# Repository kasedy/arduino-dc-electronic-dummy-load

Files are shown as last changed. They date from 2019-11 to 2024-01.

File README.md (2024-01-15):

# Arduino DIY: constant current electronic dummy load 

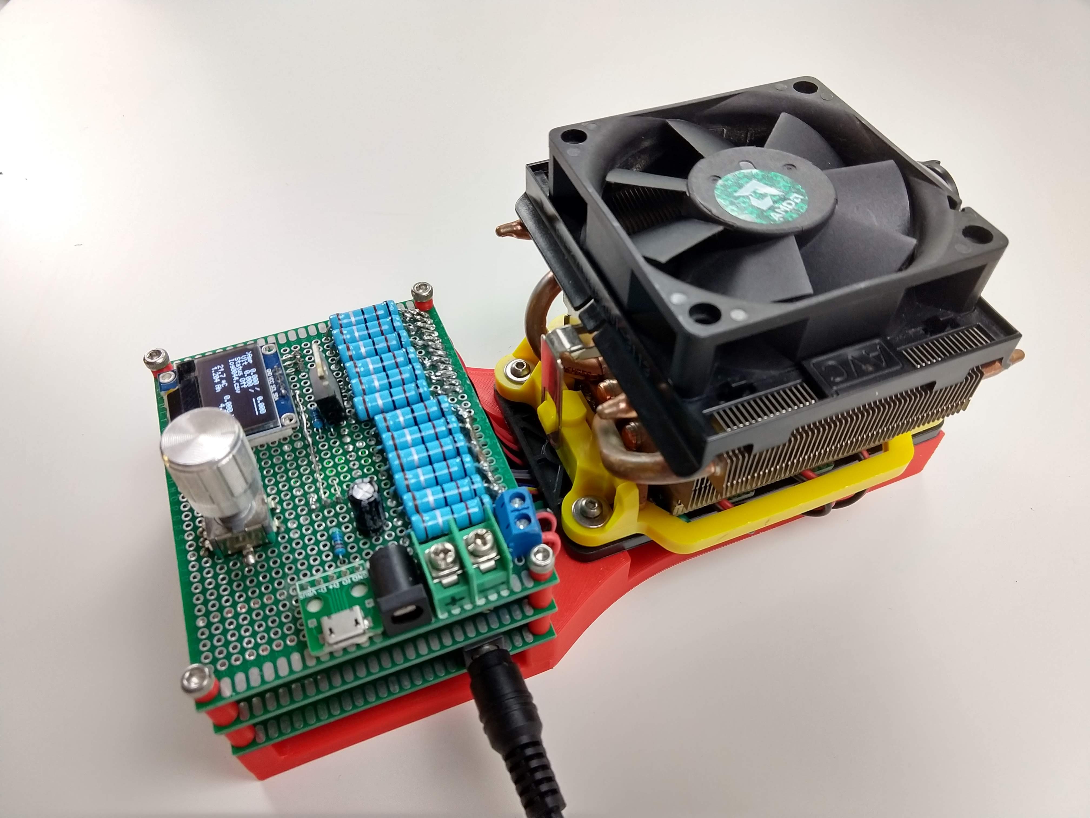
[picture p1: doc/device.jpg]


# Absolute Maximum Ratings

* Maximum Input Load Voltage - 32V
* Maximum Input Load Current - 16A
* Maximum Input Power Dissapation - 120W
* Power Source - 12V power addapter
* Minimum load current draw - 50mA
* Constant current resolution - 1mA
* Current reading error (limited by INA219 ADC resolution) - 5mA
* Voltage reading error (limited by INA219 ADC resolution) - 5mV

# Features

* Doesn't require PCB manufacturing and can be assembled on a perf board
* Multi layer stacked design to reduce the circuit size
* Using prebuilt Arduino modules reduces assemble effort
* Bright OLED display with intuitive user interface
* Writes discharge current and voltage values into microSD card
* Fully customizable

# Part list
1. 12V fan with a heat sink. It should have PWM speed control function. I used stock CPU fan from AMD FX-8350 processor as it was laying in a junk box for a long time after I installed water cooling to my desctop PC.
2. CPU cooling Fan Holder for AMD AM3. Bought on [Aliexpress](https://www.aliexpress.com/wholesale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).
3. Resistor 0.1R 3W - 12 pices. [Aliexpress](https://www.aliexpress.com/wholesale?catId=0&initiative_id=SB_20191124000008&SearchText=Resistor+0.1+3W)
4. Arduino nano. [Aliexpress](https://www.aliexpress.com/wholesale?catId=0&initiative_id=SB_20191124000043&SearchText=Arduino+nano)
5. Electrolytic capacitors 470uf and 47uf (2 pcs)
6. High current logic level N-Channel mosfet. I used IRF1404 (7 pcs) as it have ultra low On-Resistance.
7. Logic level mosfet to switch on and off the fan. I used AO3400 with a SOT23-to-DIP adapter PCB.
8. Male, female and 90-degree bended pin headers.
9. Rotary encoder.
10. SSD1306 LCD display
11. Diode to restrict reverse current coming from the fan. I belive pretty much any will work. I used M1 smd diode. But through-hole will also fit.
12. INA219 module will measure voltage and current.
13. MicroSD card module.
14. Some 2mm duck tape to palce as a buffer between perboard and arduino modules.
15. LM385P dual operational amplifier (3 pcs) and hole female header
16. Bunch of 1/4W through-hole resistors.
17. 7x9 cm perfboard (4 pcs)
18. Thermal conductive paste or tape.
19. Wire.
20. Connectors KF7.62, KF301-5.0-2P, 5.5x2.1mm Female DC Power Jack, 
21. 1kOm potentiometer.
22. 40mm M3 screw (4 pcs).
23. I used thermistor to measure heat sink temperature, but LM35 temperature sensor will be the easier solution as it doesn't requere calibration.

# Tools
1. Soldering iron
2. Flux
3. Soldering wire
4. Multimeter

# Assembly instructions

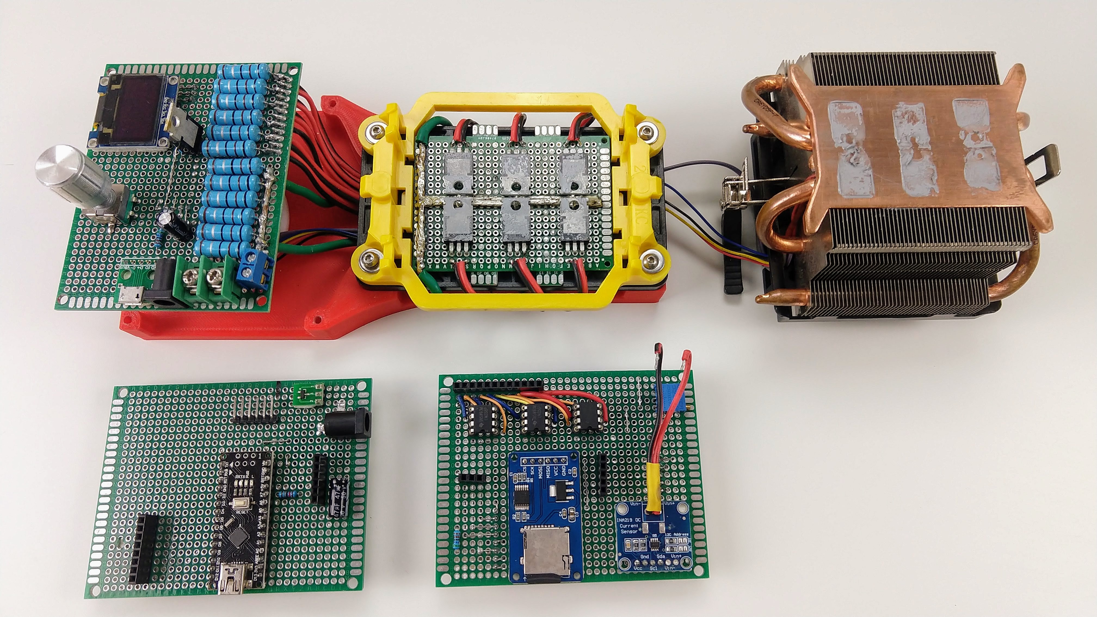
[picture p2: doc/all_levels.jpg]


# Design justification

## 12V power supply
12V power supply is less convinient than 5V but there are several reasons why it was used. First of all LM385 operational amplifier shows more stable work when powered from 12V. Also it allows to use much bigger variety of N-channel MOSFET as a heat element with a gate voltage hight than 5V and not to be bound to logic level MOSFET. The other reason is that PC fans work from 12v.

## 120W is not enough
Current design utilize 6 cascades. Each cascade includes opperational amplifier, 0R1 resistor and n-channel MOSFET. Cheap low-quality MOSFETs from Aliexpress can handle about 20W. You can get better MOSFET transistor or add more cascades. Feel free to extend the design.

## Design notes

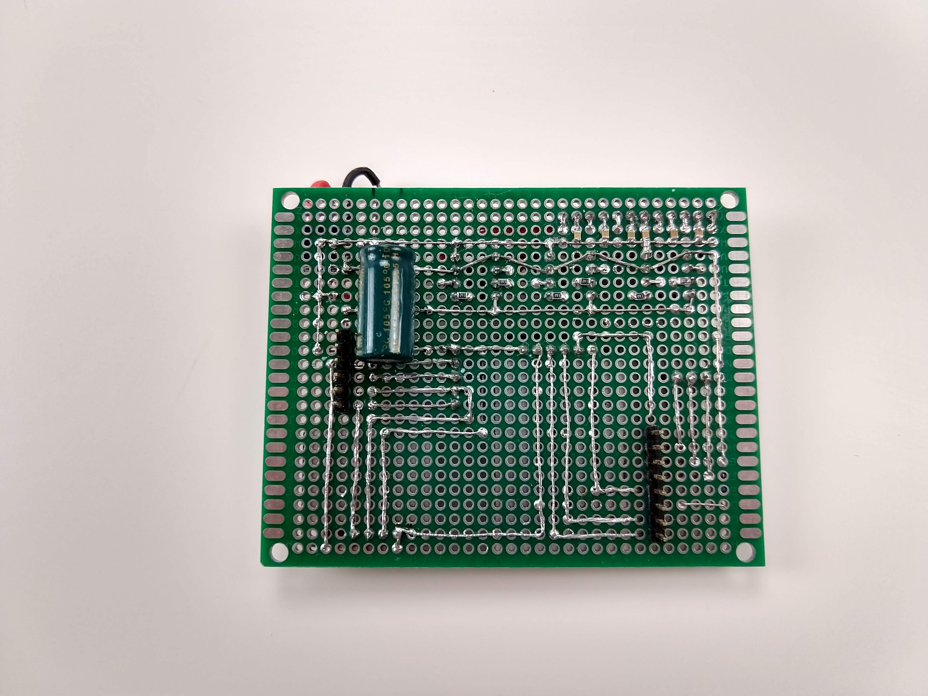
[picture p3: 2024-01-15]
doc/level_2/IMG_20191124_163301046_HDR.jpg

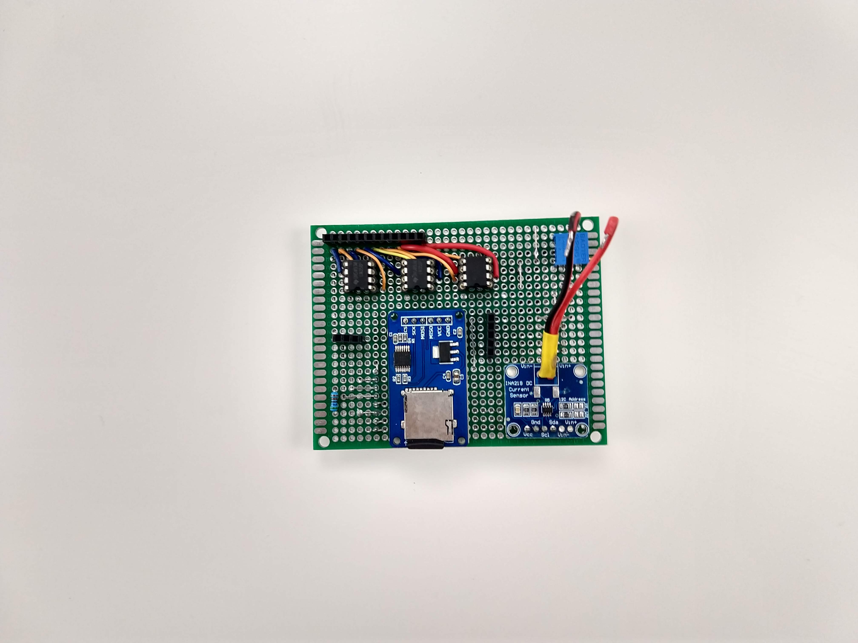
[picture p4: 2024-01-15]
doc/level_2/IMG_20191124_163133878_HDR.jpg

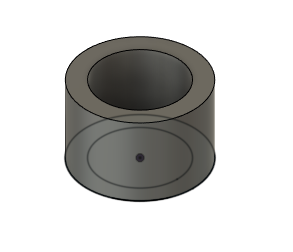
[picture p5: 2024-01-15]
doc/3d models/spacer.png

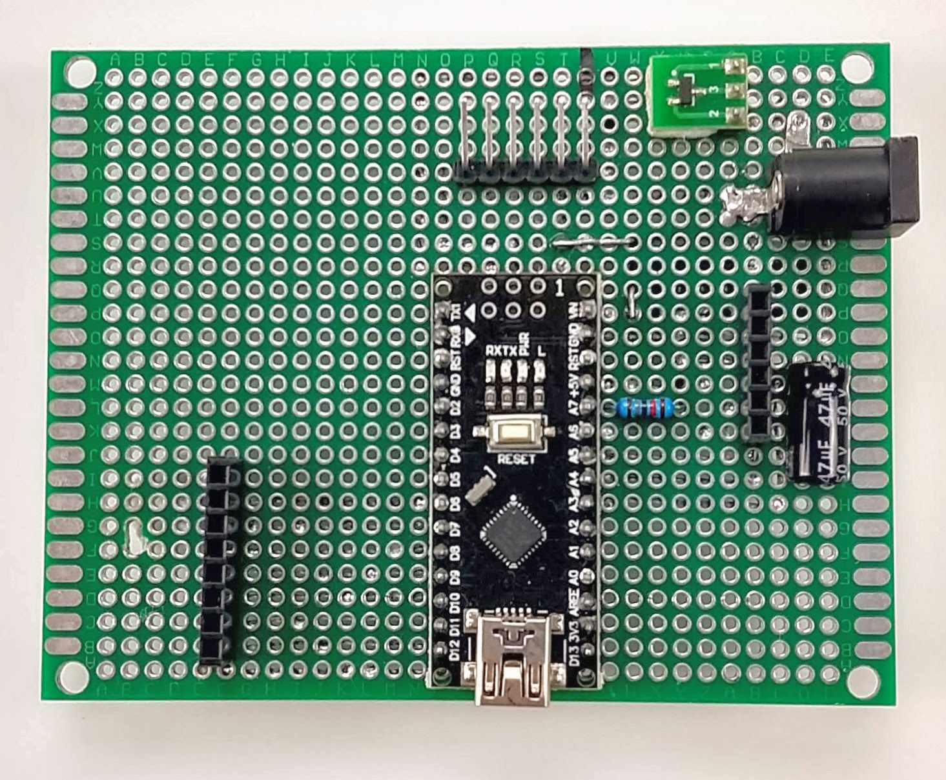
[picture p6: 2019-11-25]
doc/level_1/front.jpg

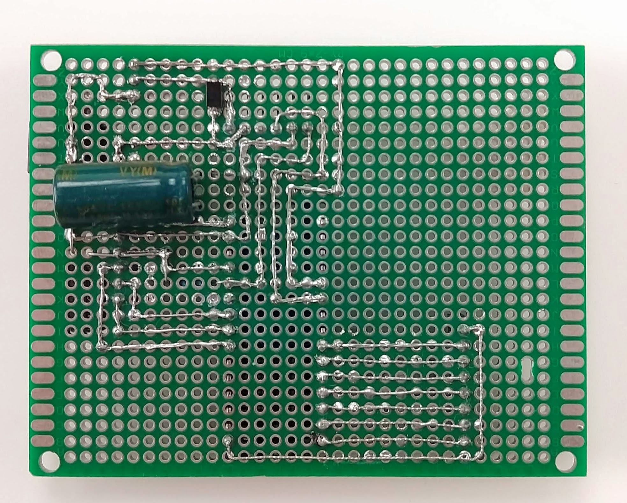
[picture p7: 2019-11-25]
doc/level_1/back.jpg

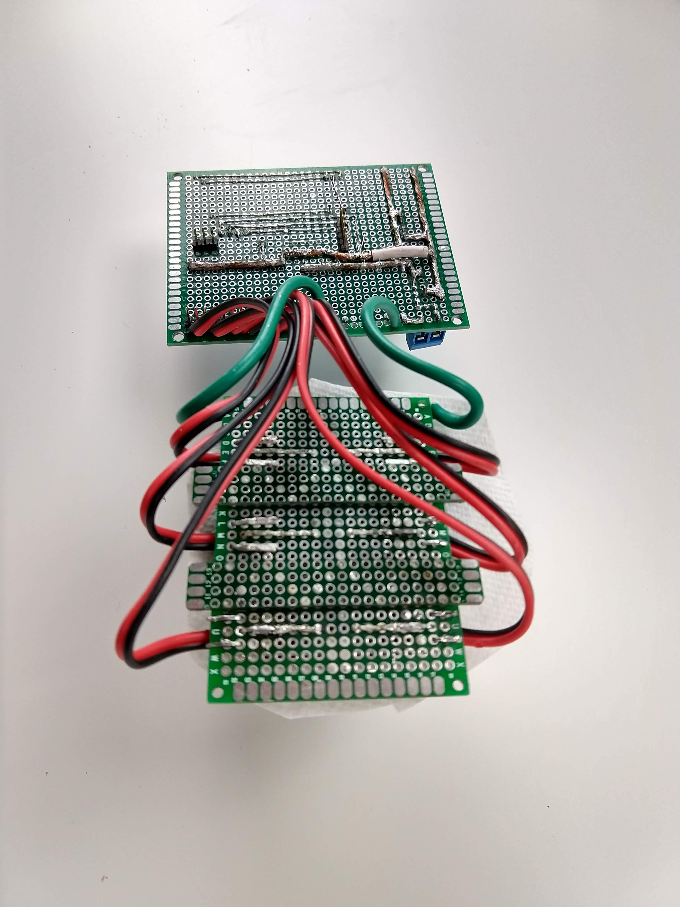
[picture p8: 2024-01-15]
doc/level_3/IMG_20191124_163827577_HDR.jpg

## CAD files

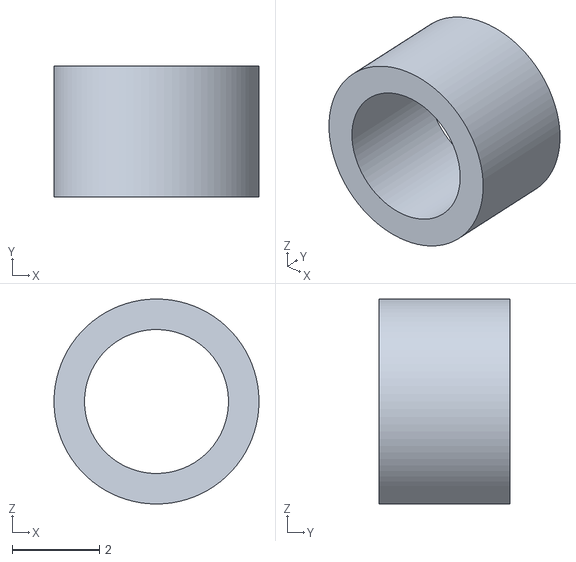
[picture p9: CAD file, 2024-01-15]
doc/3d models/spacer.stl
4.70 x 3.00 x 4.70

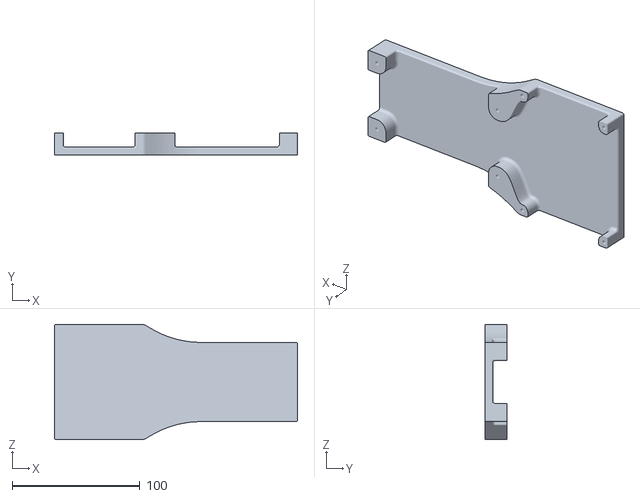
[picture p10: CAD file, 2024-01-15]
doc/3d models/foundation.stl
190.0 x 17.0 x 90.0

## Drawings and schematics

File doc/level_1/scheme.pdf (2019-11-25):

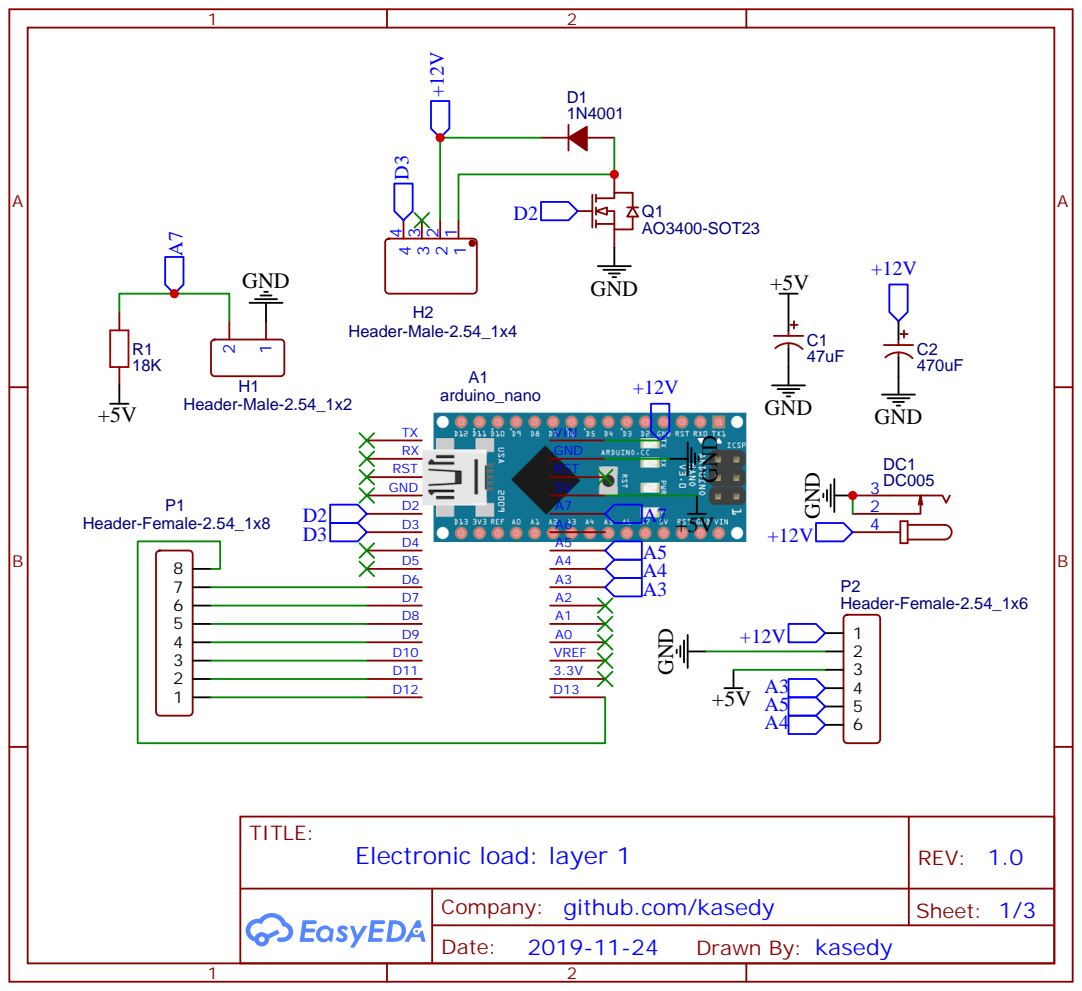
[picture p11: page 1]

Company: github.com/kasedy

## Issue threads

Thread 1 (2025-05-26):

Lack of detail

StasDeSante, 2025-05-26:
Hey, I'm currently trying to give your electronic load a go. But the lack of information in here is soul crushing. Maybe you could release a schematic or anything really? 🥺

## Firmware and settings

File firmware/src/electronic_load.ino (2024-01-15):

#include <Wire.h>
#include <ClickEncoder.h>
#include <SSD1306Ascii.h>
#include <SSD1306AsciiWire.h>
#include <MemoryFree.h>

#include "constants.h"
#include "menu_navigator.h"
#include "system_state.h"
#include "managers.h"

SSD1306AsciiWire oled;

ClickEncoder encoder(ENCODER_PIN_LEFT,
                     ENCODER_PIN_RIGHT,
                     ENCODER_PIN_BTN,
                     4);

uint32_t lastGaugeUpdateTime = 0;
uint32_t loopProcessedLastTime = 0;

MenuNavigator menuNavigator = MenuNavigator(encoder, oled);

ISR(TIMER1_OVF_vect)
{
  encoder.service();
}

void setup() {
  Serial.begin(9600);
  Serial.println(F("Setup Start!"));

  randomSeed(analogRead(UNUSED_ANALOG_PIN));

  PersistenceStateManager::setup();
  AmperagePinManager::setup();
  EmergencyManager::setup();
  FanManager::setup();
  FanTemperatureReader::setup();
  GaugeReader::setup();
  SdCardLogger::setup();

  setupOledDisplay();

  // Timer1 is 16 bit, up to 65536
  // None-inverted mode for pin 10
  TCCR1A = _BV(COM1B1); 
  // Fast PWM mode 14 with ICR1 as TOP, scale x1
  TCCR1A |= _BV(WGM11);
  TCCR1B = _BV(WGM13) | _BV(WGM12) | _BV(CS10); 
  // Frequency = 16MHz / 1 scale / 1 fast mode / 16000 = 1Kz
  ICR1 = MAX_PWM_DUTY_CYCLE;
  // interrupt is attached
  TIMSK1 = _BV(TOIE1); 

  Serial.print(F("Memory left: "));
  Serial.print(freeMemory());
  Serial.println(F(" bytes"));
  Serial.println(F("Setup end! "));

  loopProcessedLastTime = millis();
}

void loop() {
  unsigned long now = millis();

  menuNavigator.processInput();
  GaugeReader::makeMeasurement();
  FanTemperatureReader::makeMeasurement();

  unsigned long timeSinceLastupdate = now - lastGaugeUpdateTime;
  bool isRefreshCycle = timeSinceLastupdate >= REFRESH_INTERVAL_MS;
  if (isRefreshCycle) {  
    lastGaugeUpdateTime = now;
    SystemState::calculateAverage(timeSinceLastupdate);
    FanTemperatureReader::updateAverageTemperatureValue();
  }

  EmergencyManager::updateOnOffState();
  AmperagePinManager::tuneDischargeCurrent(isRefreshCycle);
  menuNavigator.updateOutput();
  FanManager::updateFanSpeed();

  if (isRefreshCycle) {
    SdCardLogger::writeSystemState();
    PersistenceStateManager::preserve();
  }
  
//  SystemState::debugPrint();

//  Serial.println(now - loopProcessedLastTime);
//  loopProcessedLastTime = now;

  SystemState::clearChangeFlag(); // should go the last
}

void setupOledDisplay() {
  Wire.begin();
  oled.begin(&Adafruit128x64, DISPLAY_I2C_ADDRESS);
  oled.setFont(MENU_FONT);
 
  oled.clear();
  oled.setContrast(255);
  oled.setCursor(0, 4);
  oled.print(F("Electronic load v1.1"));
  delay(2000);
  oled.clear();
}

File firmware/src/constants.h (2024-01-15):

#define DISPLAY_I2C_ADDRESS 0x3C
#define INA219_I2C_ADDRESS 0x40

#define MENU_FONT font5x7

#define FONT_W MENU_FONT[2]
#define FONT_H (MENU_FONT[3] + 1)

#define ENCODER_PIN_LEFT 7
#define ENCODER_PIN_RIGHT 8
#define ENCODER_PIN_BTN 6

// Limited by INA219 (+26V)
#define EMERGENCY_VOLTAGE 25000

#define VOLTAGE_REFERENCE 5.08 // 5v pin mesurment gave reference voltage

#define REFRESH_INTERVAL_MS 1000

#define THERMISTOR_PIN A7
#define THERMISTOR_NOMINAL 47900
#define TEMPERATURE_NOMINAL 25
#define B_COEFFICIENT 3950
#define THERMISTOR_SERIES_RESISTOR 17650

#define FAN_PWM_PIN 3 // can not be changed
#define FAN_ON_OFF_PIN 2
#define FAN_START_TEMPERATURE 35
#define FAN_STOP_TEMPERATURE 30
#define FAN_FULL_SPEED_TEMPERATURE 75
#define EMERGENCY_TEMPERATURE 85

#define UNUSED_ANALOG_PIN A0

// Should give 1MHz to process rotary encoder events every 1ms
#define MAX_PWM_DUTY_CYCLE 16000
#define MIN_CURRENT_MA 50 // 1 is munimum
// Max curret matches PWM resolution to have simple conversion
// in AmperagePinManager.
#define MAX_CURRENT_MA MAX_PWM_DUTY_CYCLE 
#define AMPERAGE_CHANGE_CORSE_STEP 100
#define AMPERAGE_CHANGE_FINE_STEP 1
#define CONTROL_CURRENT_PIN 10 // can not be changed

#define SD_CARD_DUMP_INTERVAL_CYCLES 5
#define SD_CARD_SC_PIN 9

#define AMPERAGE_ON_OFF_PIN A3
#define EMERGENCY_AMPERAGE 3150
#define NOICE_AMPERAGE 15
#define NOISE_VOLTAGE 15

#define ENABLE_AMPERAGE_CALIBRATION false

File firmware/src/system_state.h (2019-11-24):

#pragma once

namespace SystemState {
  void setup();

  void calculateAverage(uint32_t timePassedMillis);
  void clearChangeFlag();
  bool isFirstLoop();
  
  uint16_t getInstantAmperage();
  uint16_t getAverageAmperage();
  void setAmperage(uint16_t value);

  uint32_t getInstantVoltage();
  uint32_t getAverageVoltage();
  void setVoltage(uint32_t value);
  
  uint16_t getDesiredAmperage();
  void setDesiredAmperage(uint16_t value);

  uint32_t getStopVoltage();
  void setStopVoltage(uint32_t value);

  int16_t getAverageTemperature();
  void setAverageTemperature(int16_t value);
  
  uint32_t getAveragePower();
  float getAverageCharge();
  float getAverageEnergy();
  void resetAverageChargeAndEnergy();
  void restoreAverageChargeAndEnergy(float averageCharge, float averageEnergy);

  bool getDeviceStatusIsOn();
  void setDeviceStatusIsOn(bool value);
  void setDeviceIsInShutDownMode(bool value);

  enum SystemParameterChanged {
    Nothing = 0,
    InstantAmperage = 1 << 0,
    AverageAmperage = 1 << 1,
    InstantVoltage = 1 << 2,
    AverageVoltage = 1 << 3,
    AverageTemperature = 1 << 4,
    AverageCharge = 1 << 5, // mAh
    AverageEnergy = 1 << 6, // mWh
    DesiredAmperage = 1 << 7,
    StopVoltage = 1 << 8,
    DeviceStatusIsOn = 1 << 9,
    DeviceIsInShutDownMode = 1 << 10,
    SdCardLogFile = 1 << 11,
    MainEmergency = 1 << 12,
    AveragePower = AverageVoltage | AverageAmperage, // mW
  };

  void setChangeFlag(SystemParameterChanged changeType);
  bool isChanged(SystemParameterChanged systemParameter);

  inline void debugPrint() {
    if (isChanged(InstantAmperage)) {
      Serial.print(F("InstantAmperage: ")); Serial.println(getInstantAmperage());
    }
    if (isChanged(AverageAmperage)) {
      Serial.print(F("AverageAmperage: ")); Serial.println(getAverageAmperage());
    }
    if (isChanged(AverageVoltage)) {
      Serial.print(F("AverageVoltage: ")); Serial.println(getAverageVoltage());
    }
    if (isChanged(AverageTemperature)) {
      Serial.print(F("AverageTemperature: ")); Serial.println(getAverageTemperature());
    }
    if (isChanged(AverageCharge)) {
      Serial.print(F("AverageCharge: ")); Serial.println(getAverageCharge());
    }
    if (isChanged(AverageEnergy)) {
      Serial.print(F("AverageEnergy: ")); Serial.println(getAverageEnergy());
    }
    if (isChanged(DesiredAmperage)) {
      Serial.print(F("DesiredAmperage: ")); Serial.println(getDesiredAmperage());
    }
    if (isChanged(StopVoltage)) {
      Serial.print(F("StopVoltage: ")); Serial.println(getStopVoltage());
    }
  }
};

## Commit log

2019-11-25 added level 1 photos and assembly instructions
    [wiring.fzz]
2024-01-15 some fix from past + many photos
    [constants.h, electronic_load.ino]
2024-01-15 added 3d models
    [foundation.stl, spacer.stl]
